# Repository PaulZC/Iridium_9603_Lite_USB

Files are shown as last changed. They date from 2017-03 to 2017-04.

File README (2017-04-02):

#########################
# Iridium 9603 Lite USB #
#########################

An untested design for a very small, lightweight, USB-powered Iridium 9603 satellite communication module.
Dimensions are 35mm x 44mm x 18mm and the populated PCB will weigh close to 33g (including the antenna).

Python 2.7 code has been tested on Windows 10 and Debian Linux (Raspberry Pi).

The USB interface is provided by a Cypress CY7C65213 USB-UART Bridge.

Power for the Iridium 9603 is provided by a Linear Technology LTC3225EDDB supercapacitor charger.

See Iridium_9603_Lite_USB.pdf for a full description of the project:
https://github.com/PaulZC/Iridium_9603_Lite_USB/blob/master/Iridium_9603_Lite_USB.pdf

The Python code can be found in Iridium_9603_Lite_USB.py
https://github.com/PaulZC/Iridium_9603_Lite_USB/blob/master/Iridium_9603_Lite_USB.py

The PCB schematic, layout and bill of materials can be found in:
https://github.com/PaulZC/Iridium_9603_Lite_USB/blob/master/Iridium_9603_Lite_USB_V1.pdf

The Eagle files can be found in:
https://github.com/PaulZC/Iridium_9603_Lite_USB/tree/master/Eagle/V1

Iridium_9603_Lite_USB.cyusb contains the configuration file for Cypress' USB Serial Configuration Utility.

This project is distributed under a Creative Commons Attribution + Share-alike (BY-SA) licence.

Enjoy!

Paul

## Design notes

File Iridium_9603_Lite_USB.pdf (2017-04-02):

Iridium 9603 Lite USB

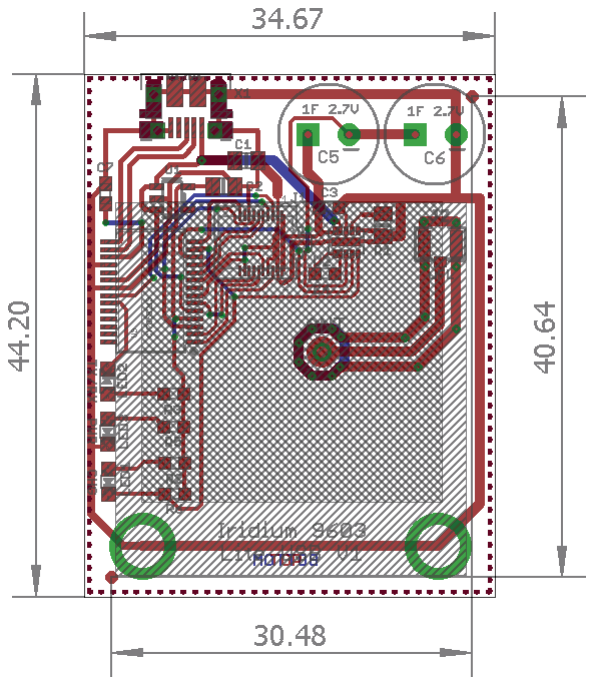
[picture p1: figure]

33 grams of satellite communication joy! Background:
Following on from the work I did on the Iridium_9603_Beacon, https://github.com/PaulZC/Iridium_9603_Beacon
which got some nice coverage on Hackaday, http://hackaday.com/2016/12/19/a-beacon-suitable-for-tracking-santas-sleigh/
I decided to set myself the challenge of designing a really small, lightweight unit that could be used to send messages via the Iridium® satellite network from high altitude balloons and other remote locations. You can already buy the fantastic RockBLOCK Mk2 from Rock7 Mobile (http://www.rock7mobile.com/products-rockblock) , which is also available from Sparkfun, (https://www.sparkfun.com/products/13745) but what if you wanted something even smaller and lighter…?
Inspiration came in the form of the new SparkFun USB UART Serial Breakout (https://www.sparkfun.com/products/13830) which features the Cypress CY7C65213 USB to UART Bridge. This chip makes all eight serial port lines available (TXD, RXD, RTS, CTS, DSR, DTR, DCD and RI) plus eight general purpose input/output (GPIO) pins that can be used to control other functions. In the Iridium_9603_Lite_USB, I use it to: provide a full USB to UART interface for the Iridium 9603 (including the Ring Indicator which can let you know a “mobile terminated” message is waiting to be collected); provide power for the 9603 via an LTC3225EDDB supercapacitor charger direct from the USB port; and use the GPIO lines for housekeeping.

I like to use Python where I can and was delighted to find that Taisuke Yamada had written a library called python-ucdev (https://github.com/PaulZC/python-ucdev) with which I was able to control the CY7C65213 GPIO pins (in manufacturing mode).
The current status is: I have a working breadboard prototype which has been tested successfully with Python 2.7 code running on Windows 10 (64-Bit) and Debian Linux (Raspberry Pi). Have a look at: https://github.com/PaulZC/Iridium_9603_Lite_USB_Prototype
The design in this repo condenses the prototype onto a small, 2-layer PCB. The dimensions are 35mm x 44mm x 18mm and the final weight will be close to 33g (including the antenna). The design is ready for manufacture and I plan to have some boards made for testing shortly.
What does the Iridium 9603 Lite USB actually do?
It enables you to send and receive short data messages anywhere using the Iridium® satellite network. The constellation of 66 cross-linked Low Earth Orbit (LEO) satellites provide high-quality data connections over the planet’s entire surface, including across oceans, airways and polar regions.
The Iridium_9603_Lite_USB could be connected to a laptop, tablet, phone or an embedded computer like a Raspberry Pi and provide a data link in areas without a mobile phone or WiFi signal.
It is the perfect solution for many tracking or remote monitoring applications.
So, what’s the catch?
The board design in this repo is currently untested. I’m quite confident that the circuit design is sound and will work since both the Iridium_9603_Beacon and the Iridium_9603_Lite_USB_Prototype work well. However, this is a new design on a single 2-layer PCB with the Taoglas Iridium patch antenna mounted on the bottom of the PCB, directly under the 9603 module itself. The patch antenna needs a continuous ground plane for best results. I achieved this on the Iridium_9603_Beacon by having the antenna mounted on its own separate PCB above the 9603. In this design the 9603 and antenna share the same PCB. Although I’ve kept the number of tracks on the bottom of the PCB – right next to the antenna – to an absolute minimum they do still break up the ground plane to some degree. There is a chance that: the 9603 transmission and reception won’t be perfect as the performance of the antenna will be degraded by some – hopefully small – amount; the transmission bursts from the antenna may couple into the PCB tracks and could cause interference and erroneous behaviour.

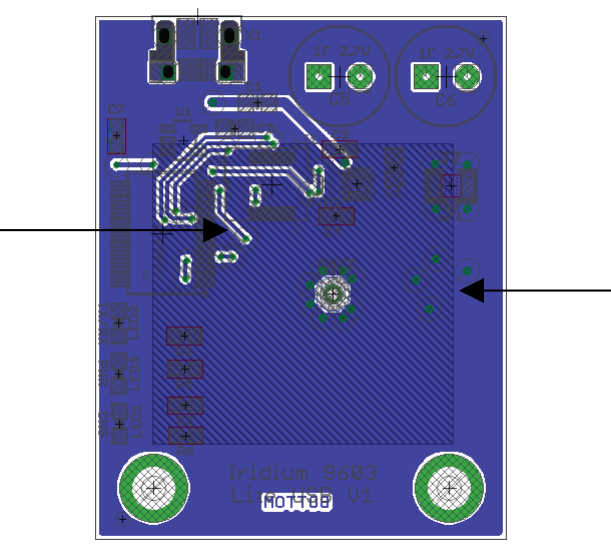
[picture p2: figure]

I’m quite confident that a 4-layer board would work perfectly, as that would allow the bottom layer to become a dedicated unbroken ground plane for the antenna. But as that would push the manufacturing costs up, I’m keen to try 2-layers first.
Surely this is good enough to be a product. Why aren’t you making and selling them? I don’t have the time or the funds to have the board CE marked and FCC approved. The 9603 itself is already approved to: ETSI EN 301 441 V1.1.1 (2000-05); ETSI EN 301 489-20 V1.2.1 (2002-11); ETSI EN 301 489-1 V1.9.2 (2011); EN61000-4-2 : 2009; EN61000-4-3 : 2006 + A1: 2008 + A2: 2010; EN61000-4-4 : 2004 + A1: 2010; EN61000-4-6 : 2009; EN55022:2006 + A1: 2007; EN60950-1:2006 + A11: 2009 + A1: 2010 + A12: 2011; FCC CFR47 parts 2 (2013), 15B (2013), and 25 (2013); Industry Canada RSS170 Issue 2, March, 2011; and Industry Canada RSS-GEN Issue 3, December, 2010. Anyone wanting to market the Iridium_9603_Lite_USB as a product would need to have the board (re)certified against the same standards. I would certainly be interested in talking to a manufacturer who would be willing to take this on as a product, look after the certification, and pay me very modest royalties in return for continued support and further software development.
Also, the PCB design has been developed using the educational version of Eagle. Anyone wanting to market the Iridium_9603_Lite_USB would need to have the commercial version of Eagle.
OK. But why make it open source? Why not keep the design to yourself?
Making the design open source is the right thing to do. Part of the design is based on the SparkFun USB UART Serial Breakout, (https://www.sparkfun.com/products/13830) the design of which is released under a Creative Commons Share-alike 4.0 licence. And so, for that reason alone, the design of the Iridium_9603_Lite_USB needs to be issued under the same licence.

Antenna outline

Tracks which
break into the
ground plane

Also, I’m making use of Python code written by Tai Yamada which was released under the GNU Lesser General Public Licence. Sharing my version of Tai’s code under the same licence is the right thing to do, both morally and legally.
If you’re still not convinced, take time to watch the following talks from the amazing people behind Sparkfun and Adafruit. You can make money from open source designs, but you need to go about it in the right way. https://www.youtube.com/watch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
Tell me about the design.
The key components of the Iridium_9603_Lite_USB are:
- Cypress CY7C65213 USB-UART Bridge (in a 28-pin SSOP package)
- http://www.cypress.com/part/cy7c65213-28pvxi
- Available from e.g. Mouser (Part# 727-CY7C65213-28PVXI)
- Iridium 9603 Module
- Available (in the UK) from e.g.:
- http://www.ast-systems.co.uk/Product-Pages/Iridium-9603-SBD— Satellite-Tracking-Transceiver.aspx (http://www.ast-systems.co.uk/Product-Pages/Iridium-9603-SBD--Satellite-Tracking-Transceiver.aspx)
- http://www.rock7mobile.com/products-iridium-sbd
- Other UK and International distributors can be found at:
- https://iridium.com/products/details/Iridium-9603?section=wtb
- Linear Technology LTC3225EDDB SuperCapacitor Charger
- http://www.linear.com/product/LTC3225
- Available from e.g. Farnell / Element14 (Part# 1715231)
- Charges two e.g. Bussmann HV0810-2R7105-R 1F 2.7V capacitors (Farnell / Element14 Part# 2148482)
- Taoglas IP.1621.25.4.A.021 Iridium Patch Antenna
- Available from e.g. Mouser (Part# 960-IP1621254A02)
The schematic, board layout and bill of materials can be found in: https://github.com/PaulZC/Iridium_9603_Lite_USB/blob/master/Iridium_9603_Lite_USB_V1.pdf (https://github.com/PaulZC/Iridium_9603_Lite_USB/blob/master/Iridium_9603_Lite_USB_V1.pdf)

The Eagle PCB files can be found in: https://github.com/PaulZC/Iridium_9603_Lite_USB/tree/master/Eagle/V1
OK. I want to build one. What do I do first?
Start by having the PCB made. I can recommend Multi-CB (https://www.multi-circuit-boards.eu/en/index.html) who will manufacture PCBs very quickly and at a very reasonable cost. It would be wise to order one or more solder paste stencils at the same time. Multi-CB will allow you to upload the Eagle files direct, avoiding the need to work with Gerber files.
The fiducials FD1 and FD2 will help you to line up the solder stencil (assuming you are using one). Populate the PCB with components C1 to X1. Ignore the non-surface mount components S1 to ANT for now. Populating the surface mount components and reflowing the solder paste is the subject of a whole different tutorial. If you plan on doing it yourself, please be aware that positioning the Samtec connector (J1) and the LTC3225EDDB (U2) will be challenging. The other components can be hand-soldered if required.
Once the surface mount components are in place, you can use a press or vice to press the two press-in nuts S1 and S2 into the bottom of the PCB. Then hand-solder the two super capacitors C5 and C6, followed by the Taoglas patch antenna ANT. The capacitors go on the top of the board, the antenna on the bottom. The antenna pin is slightly off-centre, make sure you orientate it correctly before using the adhesive pad to stick it to the board.
OK. Now what?
The next step is to configure the CY7C65213. Don’t attempt to install the 9603 yet. Read Sparkfun’s CY7C65213 hookup guide:
- https://learn.sparkfun.com/tutorials/sparkfun-usb-uart-breakout-cy7c65213-hookup-guide (https://learn.sparkfun.com/tutorials/sparkfun-usb-uart-breakout-cy7c65213-hookup-guide)
You will also want to download and install Cypress’ USB-Serial Software Development Kit:
- http://www.cypress.com/documentation/software-and-drivers/usb-serial-software-development-kit (http://www.cypress.com/documentation/software-and-drivers/usb-serial-software-development-kit)
You might find Cypress’ CY7C65213 Reference Design documentation useful too:
- http://www.cypress.com/documentation/development-kitsboards/cyusbs232-usb-uart-lp-reference-design-kit (http://www.cypress.com/documentation/development-kitsboards/cyusbs232-usb-uart-lp-reference-design-kit)

Plug in your board, run the USB Serial Configuration Utility and check that it detects the CY7C65213:

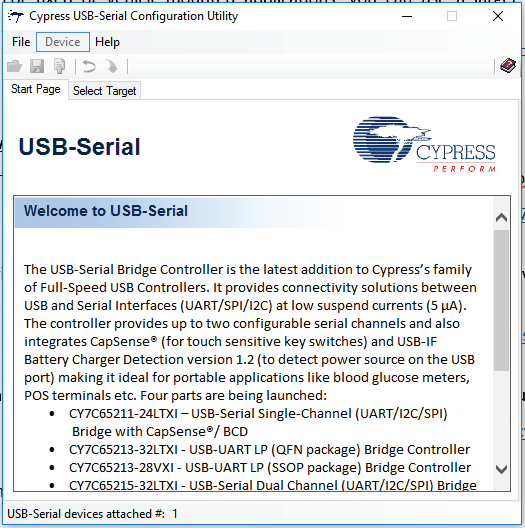
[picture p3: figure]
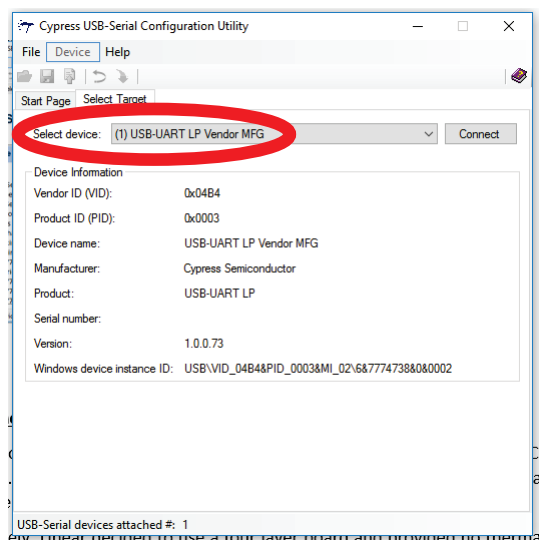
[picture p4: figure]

Select the “USB-UART LP Vendor MFG” and connect to it. Click the “Open Configuration from Device” icon to ensure the default device configuration has been read successfully. Click the Save icon and save the default configuration using a filename like “CY7C65213_Default.cyusb”. That way, you can restore the default configuration if you need to.

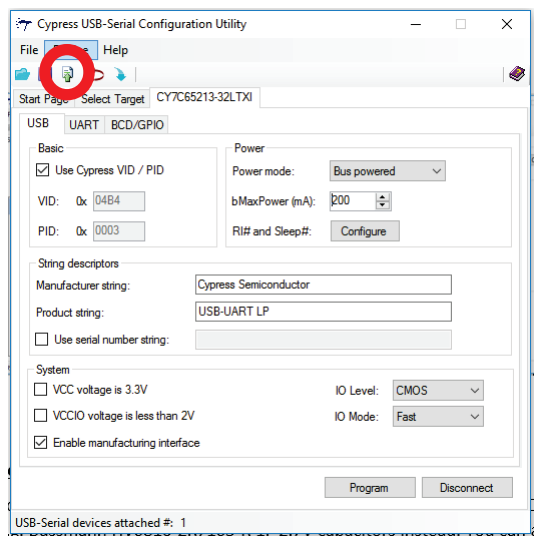
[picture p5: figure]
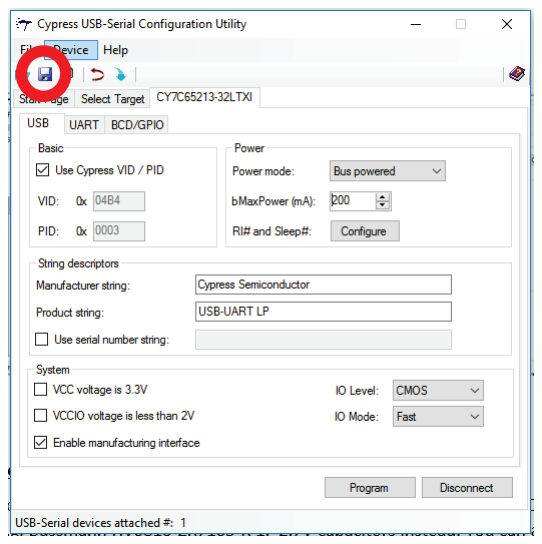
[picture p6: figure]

Set “bMaxPower (mA) to 200”:

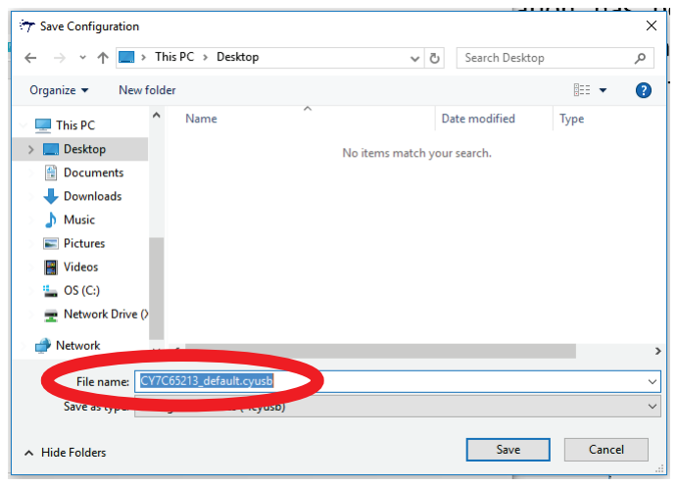
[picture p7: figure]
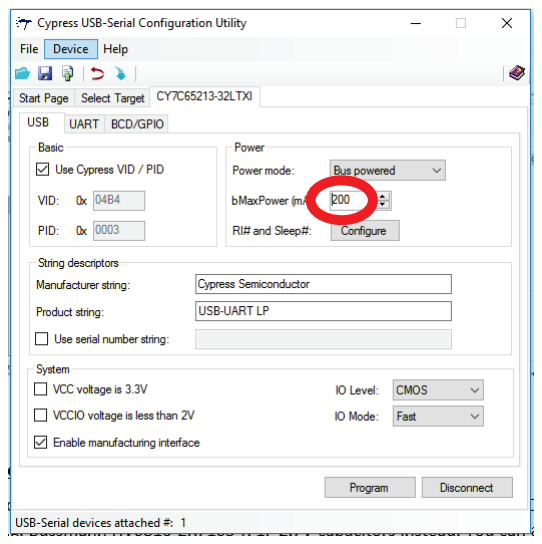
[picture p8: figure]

Click the Configure button next to “RI# and Sleep#”. Leave RI enabled. Set “Sleep#” and “Power#” to “Not enabled”, then click OK. (You could leave Sleep# set to GPIO 04 if you want the USB host to be able to put the supercapacitor charger to sleep automatically, but I haven’t tested this as yet.)

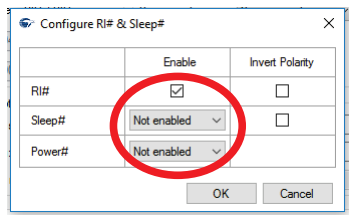
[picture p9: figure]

Select the UART tab and then click the Configure button next to “Mode”:

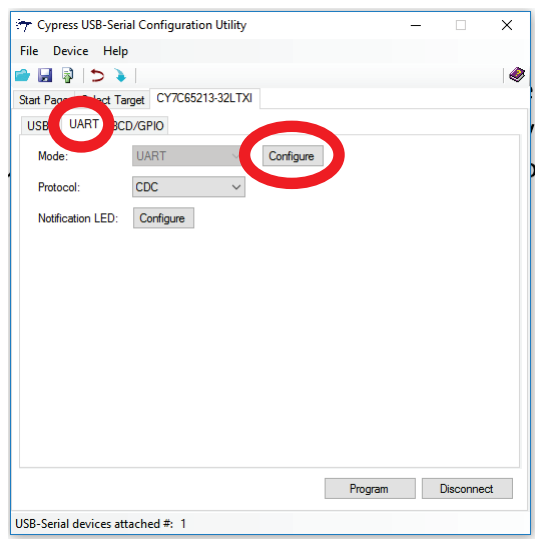
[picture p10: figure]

Set the Baud rate to 19200, untick the “Disable CTS…” box and then click OK.

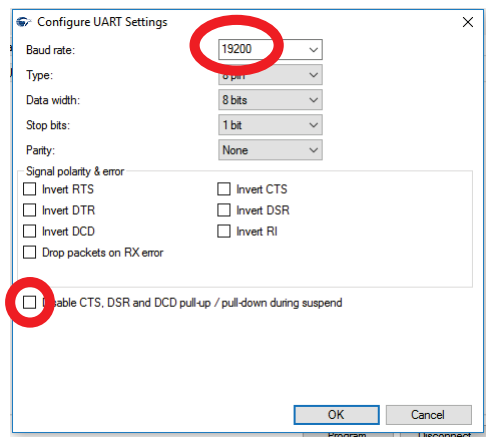
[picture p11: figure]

Click the Configure button next to “Notification LED”. Set “RX notification” and “TX notification” to “None”. Set “RX or TX notification” to “GPIO 00”. Then click OK.

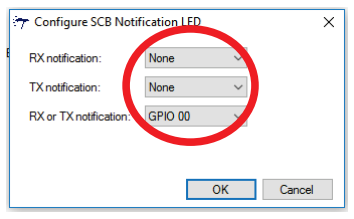
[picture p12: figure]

Select the BCD/GPIO tab and then click the Configure button next to “Unused GPIOs’ drive mode”:

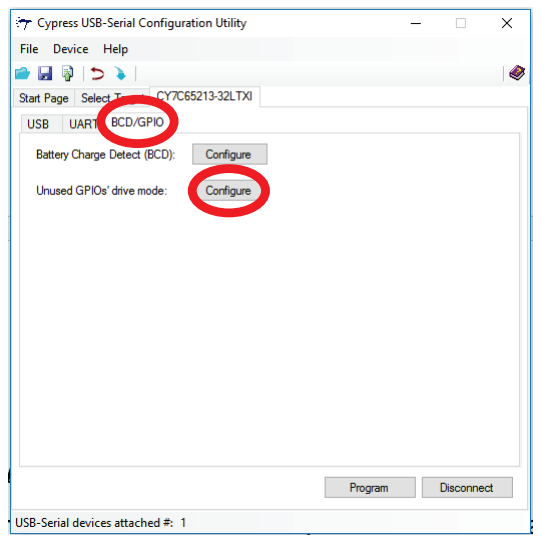
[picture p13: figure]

Select the following drive modes then click OK:
- GPIO 01: “Drive 0” (this will turn the 9603 off by default)
- GPIO 02: “Input” (for the supercapacitor charger PGOOD signal)
- GPIO 03: “Input” (for the Iridium 9603 Network Available signal)
- GPIO 04: “Drive 1” (this will power up the supercapacitor charger by default)
- (GPIO 04 will be missing from the list if it is allocated to Sleep#)

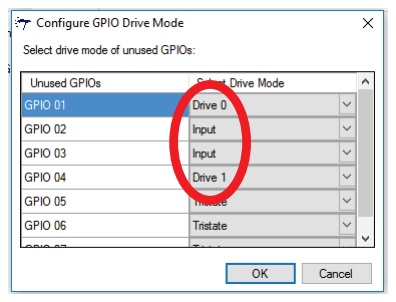
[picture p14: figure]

Click “Program” to program these settings into the CY7C65213. Check that the programming is successful.

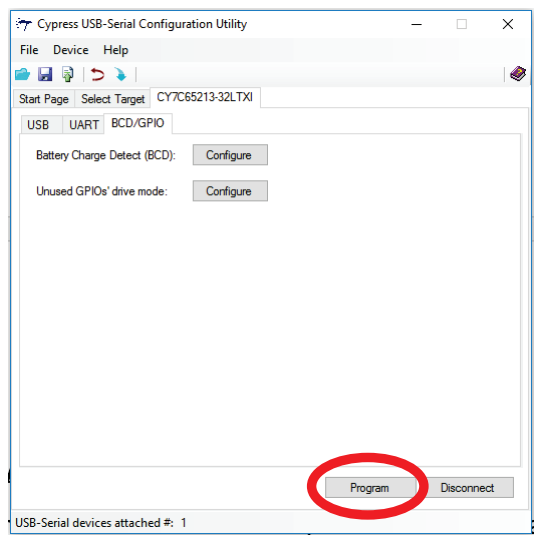
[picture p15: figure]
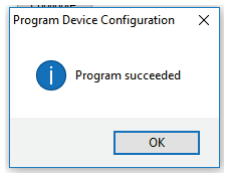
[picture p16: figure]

Save the configuration into a new .cyusb file called something like Iridium_9603_Lite_USB.cyusb.

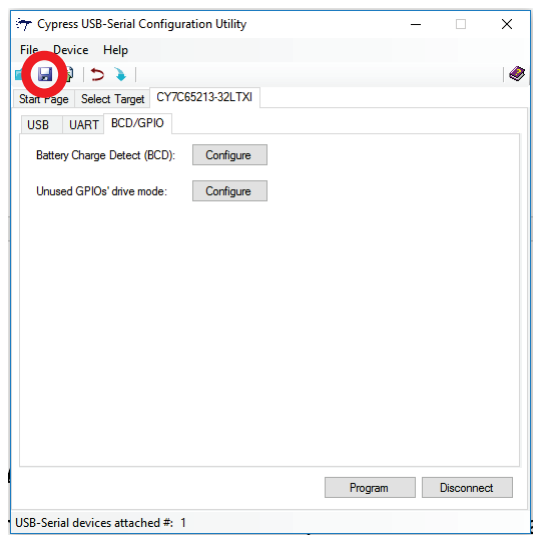
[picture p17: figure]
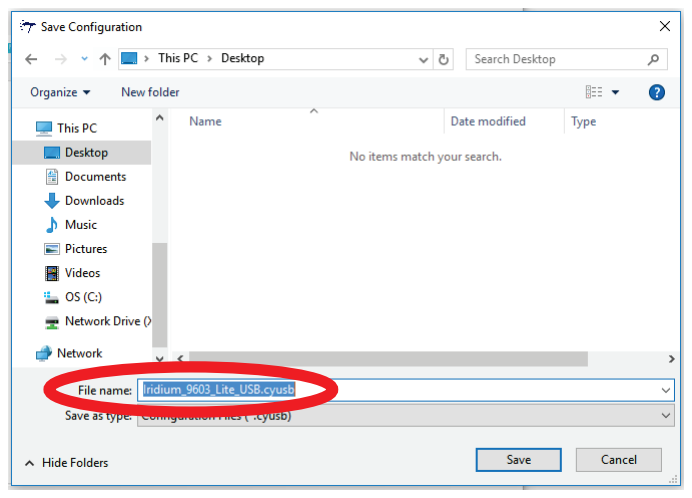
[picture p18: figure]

Finally, click “Disconnect” and unplug the CY7C65213. It will use the new configuration the next time it is powered up.

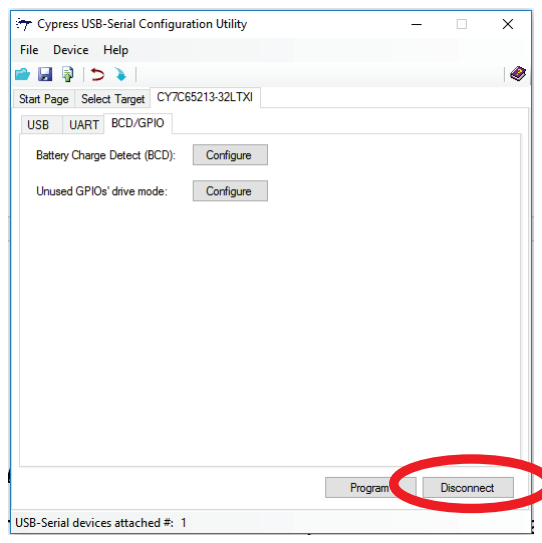
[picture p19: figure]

OK. The CY7C65213 is configured. Now what do I do?
At this point I would recommend testing the supercapacitor charger and to do that you will need to run the Python code Iridium_9603_Lite_USB.py: https://github.com/PaulZC/Iridium_9603_Lite_USB/blob/master/Iridium_9603_Lite_USB.py (https://github.com/PaulZC/Iridium_9603_Lite_USB/blob/master/Iridium_9603_Lite_USB.py)
You will also need to clone or download:
- https://github.com/PaulZC/python-ucdev
- Run “python setup.py install” to install the library, or make sure the cy7c65213 sub-directory is copied into the same directory as Iridium_9603_Lite_USB.py If you haven’t installed it before, you will also need CFFI:
- https://pypi.python.org/pypi/cffi?
- http://cffi.readthedocs.io/en/latest/
The code won’t work without Cypress’ cyusbserial.dll (on Windows machines):
- The dll gets installed as part of the SDK (see above)
- You will usually find the 64-Bit Windows version in:
- C:\Program Files (x86)\Cypress\USB-Serial SDK\library\cyusbserial\x64
- The 32-Bit Windows version is usually found in:
- C:\Program Files (x86)\Cypress\USB-Serial SDK\library\cyusbserial\x86 There are instructions in the python-ucdev repo to show you how to get the code up and running under Linux (Debian on Raspberry Pi).
Run the code. The code will power up the supercapacitor charger and you can check that the capacitors charge to 4.8V (2.4V each; flip the board over and probe the pins of C5 and C6, or probe carefully on C3 on the top of the board). The code will stall at “Writing AT Expecting OK”. That’s fine. Press Ctrl-C to exit the code. If the code keeps printing “Waiting for PGOOD to go high...” for more than a minute then you have a fault you need to investigate.
The green “PWR” LED will light up whenever the board is powered. The yellow “TX/RX” LED will flash whenever there is activity on the USB interface. The red “CHG” LED will light up while the supercapacitors are charging and go out once they are charged.

OK. Is it time to mount the 9603?
Yes. Make sure the board is unplugged and wait for C5 and C6 to discharge. This can take a while! If you’re feeling brave, you can use a 100R resistor to ‘short out’ C3. Take anti-static precautions. Ideally you should be wearing a wrist strap.
Rotate the PCB so the edge with the uFL connector is facing you. Flip the 9603 over and lie it to the left of the PCB with its uFL connector facing you. Carefully connect the short Molex uFL cable to the 9603 and then to the uFL connector on the PCB. Gently pick up the 9603, bend the Molex cable right of centre and gently press the 9603 onto the Samtec connector. Now position the two spacers between the 9603 and the press-in nuts and finally use the two 2-56 screws to secure the 9603 in position. Don’t over-tighten the screws.
Reconnect the board, run the code again and your first message should be delivered to the email address you registered when you purchased your 9603 module. Don’t forget you need to flip the board over and give the patch antenna a clear view of the sky. It is unlikely to work indoors.
How are the GPIO pins used?
- GPIO0 will flash the “TX/RX” LED whenever data is transmitted or received over the USB port
- GPIO4 is used to enable or disable the LTC3225EDDB supercapacitor charger
- Hold GPIO4 high to enable the LTC3225EDDB
- Low puts the LTC3225EDDB into Shutdown
- GPIO2 is connected to the LTC3225EDDB PGOOD signal
- High indicates that the power is good (CHG LED off)
- Low indicates that the capacitors are still charging (CHG LED on)
- GPIO1 is used to turn the Iridium 9603 on (high) or off (low)
- At power-up, hold GPIO1 low until GPIO2 (PGOOD) goes high
- GPIO3 is connected to the Iridium 9603 Network Available signal
- This pin can be monitored to check whether the 9603 can see an available satellite network
- High indicates that the network is available
- Monitoring this pin is equivalent to issuing an AT+CSQ command

Are there any tricks I need to know?
The main one is that the Iridium 9603 will refuse to communicate unless both the RTS and DTR pins are pulled low. Using pyserial, you need to set both pins to “1” to produce a low output:
- set_RTS(1)
- set_DTR(1)
What other resources do you recommend?
Here are a few useful links:
- http://www.makersnake.com/rockblock/
- https://cdn.sparkfun.com/datasheets/Wireless/General/IRDM_ISU_ATCommandReferenceMAN0009_Rev2.0_ATCOMM_Oct2012.pdf (https://cdn.sparkfun.com/datasheets/Wireless/General/IRDM_ISU_ATCommandReferenceMAN0009_Rev2.0_ATCOMM_Oct2012.pdf)
- https://www.networkinv.com/wp-content/uploads/2012/08/Iridium-9603-Developers-Guide-v2-1.pdf (https://www.networkinv.com/wp-content/uploads/2012/08/Iridium-9603-Developers-Guide-v2-1.pdf)
Will the Iridium 9603 Lite USB really weigh 33g?
Yes, I think so. Here is how the mass estimate breaks down:
- PCB (estimate): | 8.3g
- Iridium 9603 Module: | 11.6g
- Iridium Antenna: | 9.3g
- Module Fixings: | 1.7g
- Super Capacitors: | 1.7g
- uFL Cable: | 0.4g
- Total: | 33g
Why do you need the Super Capacitors?
The Iridium 9603 module draws a peak current of 1.3A when transmitting its short data bursts. That’s too much for a standard USB port. The LTC3225 super capacitor charger draws 150mA from the USB port to charge two 1F 2.7V capacitors, connected in series, to 4.8V. The capacitors then deliver the 1.3A to the module when it sends the data burst.

Can I alter the 150mA charge current?
Yes. Replacing R1 (12K) with a 60.4K resistor will limit the charge current to 30mA: Charge Current (A) = 1800 / R1 The capacitors will of course take much longer to charge. Consult the LTC3225EDDB datasheet for further details. You can then reduce the CY7C65213 bMaxPower setting to match.
What data can I send and receive?
“Mobile Originated” messages – messages sent from the 9603 – can be up to 340 bytes and sent as text or binary data.
“Mobile Terminated” messages – messages sent to the 9603 – can be up to 270 bytes. You can receive MO data as an email attachment from the Iridium system. The email itself contains extra useful information:
- Message sequence numbers (so you can identify if any messages have been missed)
- The time and date the message session was processed by the Iridium system
- The status of the message session (was it successful or was the data corrupt)
- The size of the message in bytes
- The approximate latitude and longitude the message was sent from
- The approximate error radius of the transmitter’s location
E.g.:
From:sbdservice@sbd.iridium.com
Sent: 20 August 2016 16:25
To:
Subject: | SBD Msg From Unit: 30043406174****
Attachments: | 30043406174****_000029.sbd

MOMSN: 29
MTMSN: 0
Time of Session (UTC): Sat Aug 20 15:24:57 2016 Session Status: 00 - Transfer OK Message Size (bytes): 61

Unit Location: Lat = 55.87465 Long = -2.37135 CEPradius = 4

Thanks!
This project wouldn’t have been possible without the open source designs and code kindly provided by:
- Sparkfun:
- The USB UART Serial Breakout CY7C65213 (Product BOB-13830)
- https://www.sparkfun.com/products/13830
- Taisuke Yamada (Tai)
- Python library for Cypress CY7C65211/CY7C65215 USB-Serial bridge
- https://github.com/tai/python-ucdev

The small print
This project is distributed under a Creative Commons Share-alike 4.0 (http://creativecommons.org/licenses/by-sa/4.0/) licence.
Please refer to section 5 of the licence for the “Disclaimer of Warranties and Limitation of Liability”.

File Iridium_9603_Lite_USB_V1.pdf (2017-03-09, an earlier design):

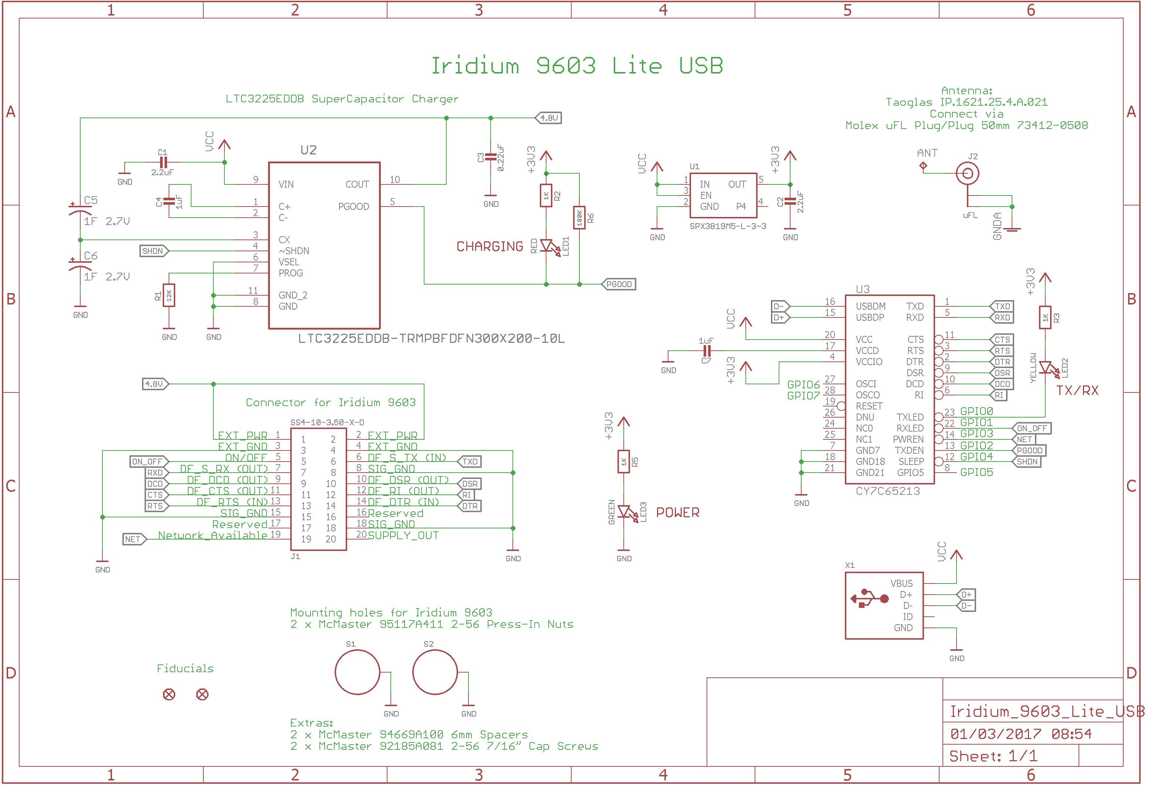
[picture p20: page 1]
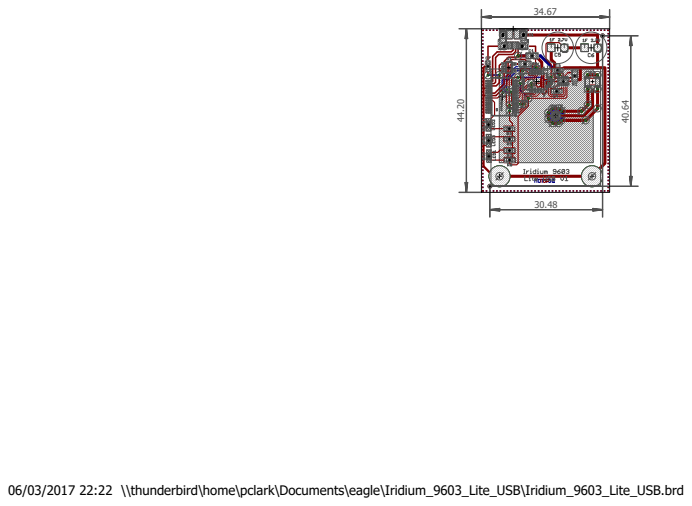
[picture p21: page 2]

06/03/2017 22:22 \\thunderbird\home\pclark\Documents\eagle\Iridium_9603_Lite_USB\Iridium_9603_Lite_USB.brd

Part | X | Y | Angle Package Value | Manufacturer | Manufacturer Part No

Farnell /
Element14
Part No Mouser Part No

McMaster
Part No | Description
FD1 | 2.29 | 1.65 | 0 | | | | | | Fiducial
FD2 | 32.77 42.29 0 | Fiducial
C1 | 13.68 36.86 0 | 0805 | 2.2uF | Multicomp | MCTT21X225K100CT | 1759477 | MultiLayer Ceramic Capacitor; 2.2uF; 10V; 0805; X5R
C2 | 11.78 34.67 0 | 0805 | 2.2uF | Multicomp | MCTT21X225K100CT | 1759477 | MultiLayer Ceramic Capacitor; 2.2uF; 10V; 0805; X5R
C3 | 20.64 32.96 0 | 0603 | 0.22uF | Multicomp | MC0603F224Z160CT | 1759019 | MultiLayer Ceramic Capacitor; 0.22uF; 16V; 0603
C4 | 20.35 27.3 | 0 | 0603 | 1uF | Walsin | 0603X105K100CT | 2496916 | MultiLayer Ceramic Capacitor; 1uF; 10V; 0603; X5R
C7 | 1.78 | 34.07 270 | 0603 | 1uF | Walsin | 0603X105K100CT | 2496916 | MultiLayer Ceramic Capacitor; 1uF; 10V; 0603; X5R
J1 | 14.9 | 29.94 0 | SS4-10-3.50 | Samtec | SS4-10-3.50-L-D-K-TR | 2085336 | Samtec SS4-10-3.50-L-D-K-TR
J2 | 30.04 29.15 270 | uFL | Hirose | U.FL-R-SMT(01) | 3908021 | HIROSE U.FL-R-SMT(01); U.FL Coaxial; Straight Jack; 50 ohm
LED1 | 2.03 | 9.75 | 180 | 2.0x1.25 RED | Kingbright | KPT-2012LVSECK-J3-PRV | 2610416 | LED; 2mm x 1.25mm; Red; 2mA; 1.8V; 625nm
LED2 | 1.94 | 18.26 0 | 2.0x1.25 YELLOW | Kingbright | KPT-2012LVSYCK-J3-PRV | 2610418 | LED; 2mm x 1.25mm; Yellow; 2mA; 1.85V; 590nm
LED3 | 1.97 | 13.97 180 | 2.0x1.25 GREEN | Kingbright | KPT-2012LVZGCK | 2610419 | LED; 2mm x 1.25mm; Green; 2mA; 2.65V; 525nm
R1 | 25.24 31.43 90 | 0805 | 12K | Panasonic | ERJ6ENF1202V | 2303661 | Chip Resistor; Thick Film; 12k; 150V; 0805; 125mW
R2 | 7.59 | 11.3 | 180 | 0603 | 1K | Yageo | RC0603FR-071KL | 9238484 | Chip Resistor; Thick Film; 1k; 50V; 0603; 100mW
R3 | 7.52 | 17.18 180 | 0603 | 1K | Yageo | RC0603FR-071KL | 9238484 | Chip Resistor; Thick Film; 1k; 50V; 0603; 100mW
R5 | 7.56 | 14.38 180 | 0603 | 1K | Yageo | RC0603FR-071KL | 9238484 | Chip Resistor; Thick Film; 1k; 50V; 0603; 100mW
R6 | 7.62 | 8.73 | 180 | 0603 | 100k | Yageo | RC0603FR-13100KL | 2309107 | Chip Resistor; Thick Film; 100k; 50V; 0603; 100mW
U1 | 7.43 | 33.72 270 | SOT23-5 SPX3819-3.3 | Exar | SPX3819M5-L-3-3/TR | 701-SPX3819M5-L-33TR | LDO Voltage Regulator; 500mA; SOT-23-5
U2 | 22.13 30 | 90 | DFN-10 | LTC3225EDDB | Linear Tech. | LTC3225EDDB#TRMPBF | 1715231 | Supercapacitor Charger
U3 | 5.65 | 25.81 90 | SSOP28 CY7C65213 | Cypress Semi. | CY7C65213-28PVXI | 727-CY7C65213-28PVXI | USB-UART LP Bridge Controller
X1 | 8.6 | 41.21 180 | Micro_USB | Amphenol_FCI | 10103594 | 2293752 | Amphenol FCI 10103594 Micro USB Type B
S1 | | | | | Press-In Nut | McMaster-Carr | 95117A411 | | 95117A411 Press-In Nut; 2-56
S2 | | | | | Press-In Nut | McMaster-Carr | 95117A411 | | 95117A411 Press-In Nut; 2-56
C5 | | | | | 1F 2.7V | Bussmann | HV0810-2R7105-R | 2148482 | Supercapacitor; 1F; 2.7V; +30%, -10%; 3.5mm Pitch
C6 | | | | | 1F 2.7V | Bussmann | HV0810-2R7105-R | 2148482 | Supercapacitor; 1F; 2.7V; +30%, -10%; 3.5mm Pitch
ANT | IP.1621.25.4.A.02 | Taoglas | IP.1621.25.4.A.02 | 960-IP1621254A02 | 25mm Iridium Patch Antenna
CABLE | | | | | | Molex | 73412-0508 | 1340201 | Molex uFL Plug/Plug 50mm 73412-0508
SPACERS_x2 | | | | | | McMaster-Carr | 94669A100 | | 94669A100 4.5mm OD x 6mm Spacers for Iridium Module
SCREWS_x2 | | | | | | McMaster-Carr | 92185A081 | | 92185A081 2-56 x 7/16" Screws for Iridium Module

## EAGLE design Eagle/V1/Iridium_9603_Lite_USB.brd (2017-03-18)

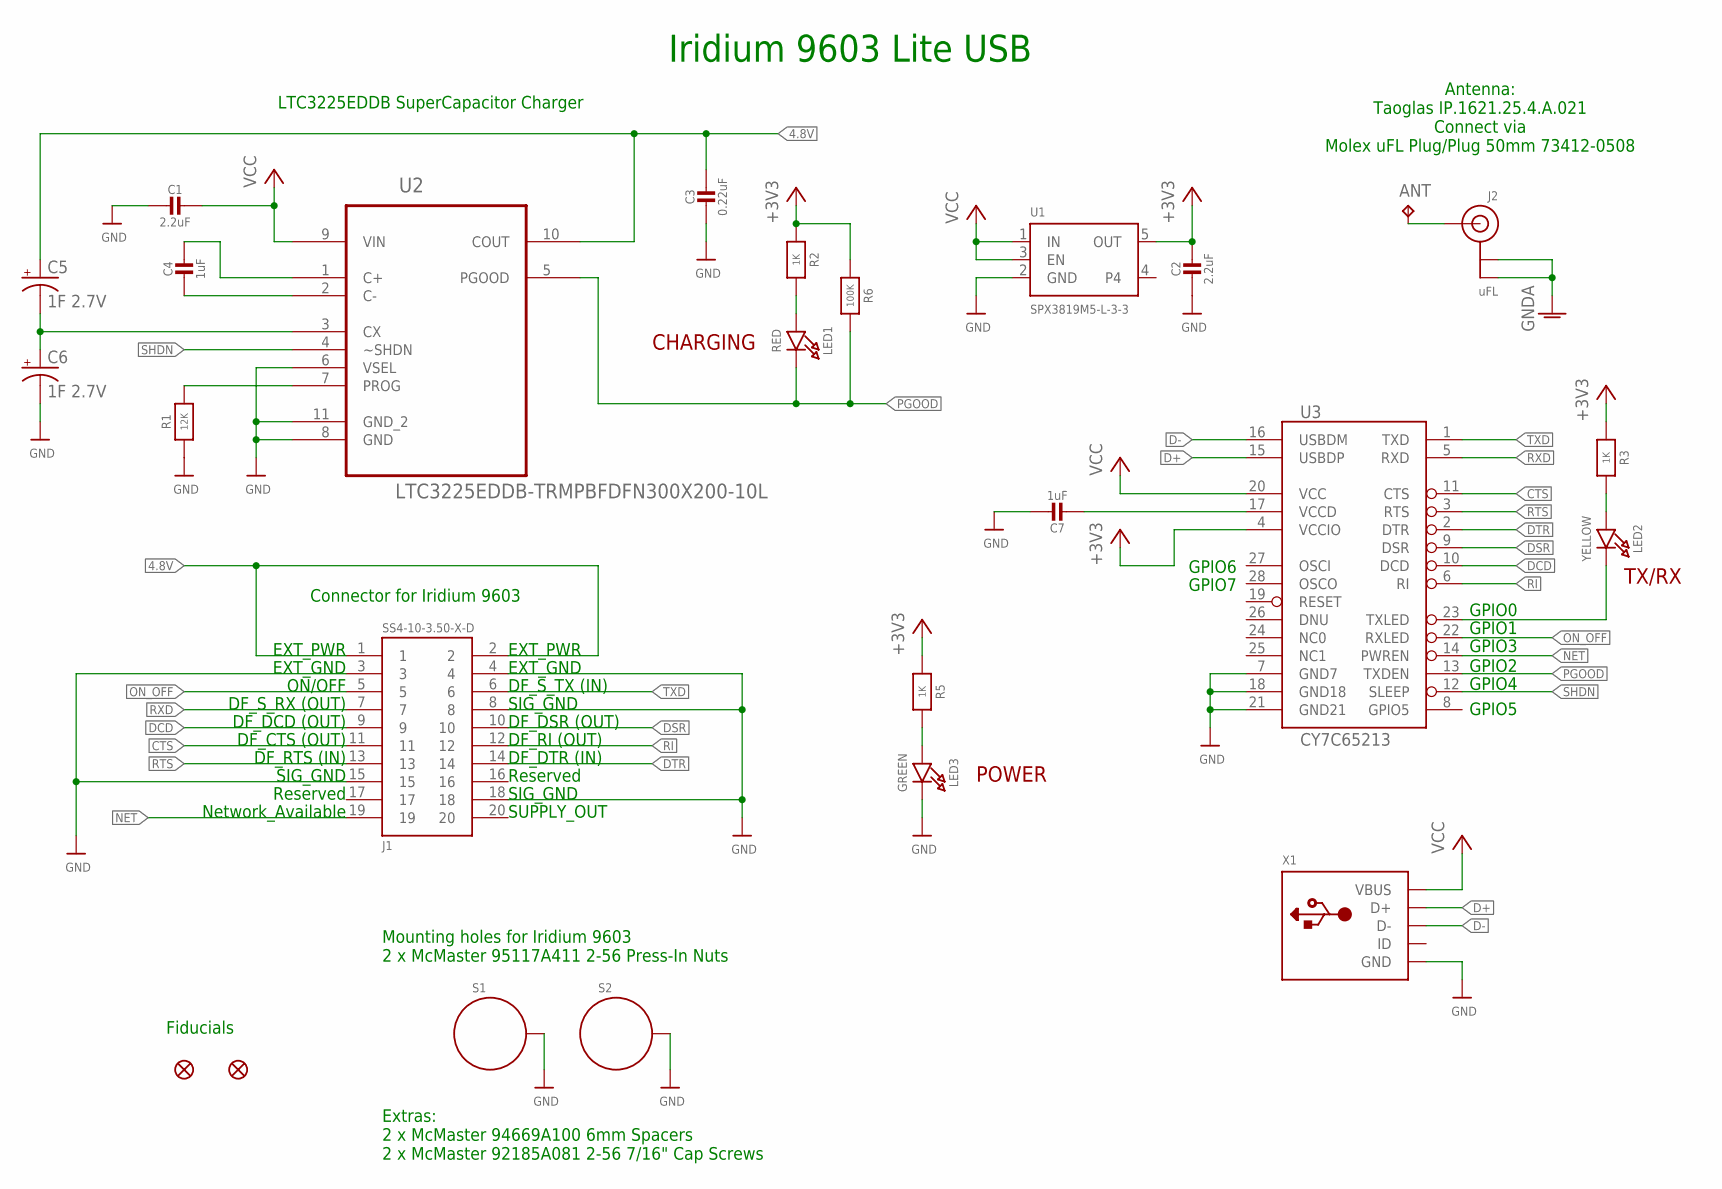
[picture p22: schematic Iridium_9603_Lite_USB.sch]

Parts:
ANT: TPB2,54; B2,54
C1, C2: 2.2uF; 0805-NO
C3: 0.22uF; 0603-NO
C4, C7: 1uF; 0603-NO
C5, C6: 1F 2.7V; CPOL-RADIAL-1F-2.7V
FD1, FD2: FIDUCIAL1X2; FIDUCIAL-1X2
J1: SS4-10-3.50-X-D
J2: uFL; U.FL
LED1: RED; CHIPLED_0805_NOOUTLINE
LED2: YELLOW; CHIPLED_0805_NOOUTLINE
LED3: GREEN; CHIPLED_0805_NOOUTLINE
R1: 12K; 0805-NO
R2, R3, R5: 1K; 0603-NO
R6: 100K; 0603-NO
S1, S2: STANDOFF_ELECTRICALMCMASTER-95117A411; STANDOFF-ELECTRICAL-MCMASTER-95117A411
U1: SPX3819M5-L-3-3; SOT23-5
U2: LTC3225EDDB-TRMPBFDFN300X200-10L; DFN300X200-10L
U3: CY7C65213; SSOP28DB
X1: USBFCI_10103594_MILL; FCI_10103594_MILL

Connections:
4.8V: C3.1, C5.+, J1.1, J1.2, U2.10 (COUT)
+3V3: C2.1, R2.1, R3.1, R5.1, R6.1, U1.5 (OUT), U3.4 (VCCIO)
ANT: ANT.TP, J2.3 (SIGNAL)
CTS: J1.11, U3.11 (CTS)
D+: U3.15 (USBDP), X1.D+
D-: U3.16 (USBDM), X1.D-
DCD: J1.9, U3.10 (DCD)
DSR: J1.10, U3.9 (DSR)
DTR: J1.14, U3.2 (DTR)
GND: C1.2, C2.2, C3.2, C6.-, C7.1, J1.3, J1.4, J1.8, J1.15, J1.18, LED3.C, R1.1, S1.P1, S2.P1, U1.2 (GND), U2.6 (VSEL), U2.8 (GND), U2.11 (GND_2), U3.7 (GND7), U3.18 (GND18), U3.21 (GND21), X1.BASE@1 (GND), X1.BASE@2 (GND), X1.GND, X1.SPRT@1 (GND), X1.SPRT@2 (GND), X1.SPRT@3 (GND), X1.SPRT@4 (GND)
GNDA: J2.1 (GND), J2.2 (GND)
unnamed: LED2.A, R3.2
unnamed: C7.2, U3.17 (VCCD)
unnamed: LED1.A, R2.2
unnamed: LED2.C, U3.23 (TXLED)
unnamed: C5.-, C6.+, U2.3 (CX)
unnamed: LED3.A, R5.2
unnamed: C4.2, U2.2 (C-)
unnamed: C4.1, U2.1 (C+)
unnamed: R1.2, U2.7 (PROG)
NC1: U3.25 (NC1)
NET: J1.19, U3.14 (PWREN)
ON_OFF: J1.5, U3.22 (RXLED)
PGOOD: LED1.C, R6.2, U2.5 (PGOOD), U3.13 (TXDEN)
RI: J1.12, U3.6 (RI)
RTS: J1.13, U3.3 (RTS)
RXD: J1.7, U3.5 (RXD)
SHDN: U2.4 (~SHDN), U3.12 (SLEEP)
TXD: J1.6, U3.1 (TXD)
VCC: C1.1, U1.1 (IN), U1.3 (EN), U2.9 (VIN), U3.20 (VCC), X1.VBUS

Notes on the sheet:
Connector for Iridium 9603
Mounting holes for Iridium 9603 2 x McMaster 95117A411 2-56 Press-In Nuts
Iridium 9603 Lite USB
EXT_PWR
EXT_GND
ON/OFF
DF_S_RX (OUT)
DF_DCD (OUT)
DF_CTS (OUT)
DF_RTS (IN)
SIG_GND
Reserved
Network_Available
DF_S_TX (IN)
DF_DSR (OUT)
DF_RI (OUT)
DF_DTR (IN)
SUPPLY_OUT
Fiducials
Antenna: Taoglas IP.1621.25.4.A.021 Connect via Molex uFL Plug/Plug 50mm 73412-0508
Extras: 2 x McMaster 94669A100 6mm Spacers 2 x McMaster 92185A081 2-56 7/16" Cap Screws
LTC3225EDDB SuperCapacitor Charger
GPIO0
GPIO1
GPIO3
GPIO2
GPIO4
GPIO5
GPIO6
GPIO7
CHARGING
POWER
TX/RX

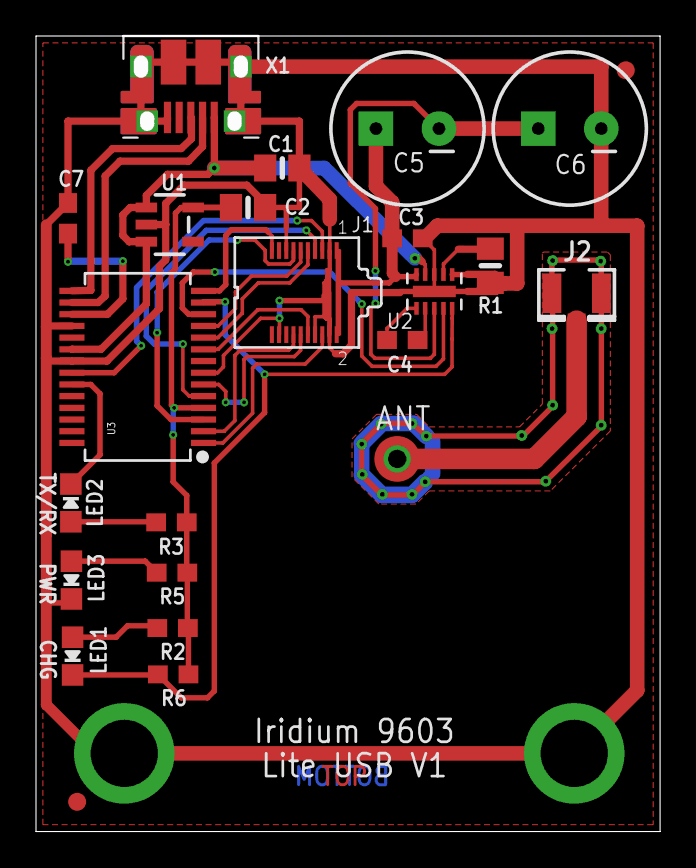
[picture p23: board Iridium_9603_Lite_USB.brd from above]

Board: 2 copper layers, 34.7 x 44.2 mm, 26 parts (0 on the bottom side), 29 nets.

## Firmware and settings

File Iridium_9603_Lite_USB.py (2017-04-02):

# Iridium 9603 Lite USB

# Tested with Python 2.7 on Windows 10 64-Bit

# Tested with Python 2.7 on Linux (Raspberry Pi) using
# https://github.com/PaulZC/python-ucdev

# 9603 power is provided by LTC3225 supercapacitor charger (charged from USB port)
# 9603 module is interfaced via a Cypress CY7C65213:
# GPIO_0 is Tx/Rx LED
# GPIO_1 is connected to 9603 ON_OFF (High=On Low=Off)
# GPIO_4 is connected to LTC3225 SHDN (High=On Low=Off)
# LTC3225 PGOOD is connected to GPIO_2 (High = Power Is Good)
# 9603 Network Available is connected to GPIO_3 (High = Network Is Available)
# All eight UART signals are connected (TXD, RXD, RTS, CTS, DTR, DSR, DCD, RI)

import serial
import time
from cy7c65213 import CyUSBSerial, CyGPIO

# Define serial port
# Check Device Manager for the correct port name (on Windows)
serport = 'COM1'
# Linux (ls /dev/tty*)
#serport = '/dev/ttyACM0'

# Point to the DLL provided by Cypress
# Windows
dll = "C:\\Program Files (x86)\\Cypress\\USB-Serial SDK\\library\\cyusbserial\\x64\\cyusbserial.dll"
# Linux
#dll = "/usr/local/lib/libcyusbserial.so"

# CY7C65213 Pin Definitions
ON_pin      = 1 # 9603 ON/OFF = GPIO_1
PGOOD_pin   = 2 # LTC3225 PGOOD = GPIO_2
NET_pin     = 3 # 9603 Network Available = GPIO_3
SHDN_pin    = 4 # LTC3225 Shutdown = GPIO_4

class IridiumUSBport(object):
    
    def __init__(self):
        print 'Opening GPIO...'
        # Load DLL provided by Cypress (Windows notation)
        self.dll = dll
        self.lib = CyUSBSerial(lib = self.dll)
        #self.dev = self.lib.find().next() # Use first device found
        self.dev = self.lib.find(vid=0x04B4,pid=0x0003).next() # Look for a specific vendor and product id
        # Access GPIO
        self.gpio = CyGPIO(self.dev)
        self.ON_pin = self.gpio.pin(ON_pin) # 9603 ON/OFF = GPIO_1
        self.PGOOD_pin = self.gpio.pin(PGOOD_pin) # LTC3225 PGOOD = GPIO_2
        self.NET_pin = self.gpio.pin(NET_pin) # 9603 Network Available = GPIO_3
        self.SHDN_pin = self.gpio.pin(SHDN_pin) # LTC3225 Shutdown = GPIO_4
        
        print 'Opening serial port...'
        self.ser = serial.Serial(serport,19200,timeout=1)

        self.CSQ = int(0)
        self.MOF = int(0)
        self.MTF = int(0)
        self.MOS = int(0)
        self.MTS = int(0)
        self.MTQ = int(0)
        
    def writeAndWait(self, data, exp):
        print 'Writing ' + data + ' Expecting ' + exp
        self.ser.write(data+'\r')
        for i in range(30):
            resp = self.ser.readline()
            if resp != '':
                if data in resp:
                    print resp[:-1]
                if exp in resp:
                    print resp[:-1]
                    break
        return resp[:-1]

    def queueMessage(self, mesg):
        print 'Queueing: ' + mesg
        self.ser.write('AT+SBDWT='+mesg+'\r')
        result = False
        for i in range(30):
            resp = self.ser.readline()
            if resp != '':
                if 'SBDWT' in resp: # AT+SBDWT is returned _after_ the OK!
                    print resp[:-1]
                    break
                if 'OK' in resp:
                    print resp[:-1]
                    result = True
                    #break
                if 'ERROR' in resp:
                    print resp[:-1]
                    break
        return result

    def initiateSBD(self):
        print 'Initiating SBD session!'
        resp = self.writeAndWait('AT+SBDI','SBDI:')
        try:
            resp_list = resp.split(",")
            mos = int(resp_list[0][-1])
            mts = int(resp_list[2][-1])
            mtq = int(resp_list[5][1:])
        except:
            mos = int(0)
            mts = int(0)
            mtq = int(0)
        self.MOS = mos
        self.MTS = mts
        self.MTQ = mtq

    def readSBD(self):
        print 'Reading text message...'
        self.ser.write('AT+SBDRT\r')
        msg = ''
        seq = 0
        for i in range(30):
            resp = self.ser.readline()
            if resp != '':
                if (seq == 2) and ('OK' in resp):
                    break
                elif (seq == 1):
                    msg = resp[:-2]
                    seq = 2
                elif (seq == 0) and ('SBDRT:' in resp):
                    seq = 1
        return msg
        
    def set_RTS(self, rts):
        self.ser.setRTS(rts)

    def set_DTR(self, dtr):
        self.ser.setDTR(dtr)

    def set_SHDN(self, shdn):
        self.SHDN_pin.set(shdn)

    def set_ON(self, onoff):
        self.ON_pin.set(onoff)

    def get_CTS(self):
        return self.ser.getCTS()

    def get_DSR(self):
        return self.ser.getDSR()

    def get_DCD(self):
        return self.ser.getDCD()

    def get_RI(self):
        return self.ser.getRI()

    def get_PGOOD(self):
        return self.PGOOD_pin.get()

    def get_NET(self):
        return self.NET_pin.get()

    def check_CSQ(self):
        resp = self.writeAndWait('AT+CSQ','CSQ:')
        try:
            csq = int(resp[-2])
        except:
            csq = int(0)
        self.CSQ = csq

    def check_SBDS(self):
        resp = self.writeAndWait('AT+SBDS','SBDS:')
        try:
            resp_list = resp.split(",")
            mof = int(resp_list[0][-1])
            mtf = int(resp_list[2][-1])
        except:
            mof = int(0)
            mtf = int(0)
        self.MOF = mof
        self.MTF = mtf

    def close(self):
        print 'Closing port...'
        self.ser.close()
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

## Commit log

2017-03-18 Updated ANT and GNDA to provide impedance of 50 Ohms
    [Iridium_9603_Lite_USB.brd, Iridium_9603_Lite_USB.sch]
2017-04-02 Added support for Linux (Debian on Raspberry Pi)

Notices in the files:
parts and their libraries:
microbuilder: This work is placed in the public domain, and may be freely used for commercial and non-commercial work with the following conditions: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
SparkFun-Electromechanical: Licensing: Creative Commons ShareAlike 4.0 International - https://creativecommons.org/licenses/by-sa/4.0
